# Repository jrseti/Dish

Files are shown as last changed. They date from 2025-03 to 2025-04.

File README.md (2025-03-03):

# Simple-Dish-Controller
Simple controller with toggle switches to move the motors of a satellite dish.

The project is to create a PCB that will control 2 motors tht will be used as the azimuth and elevation motors of a satellite dish. The direction will allow controlling simple movement for each motor, forward, reverse, still, all at one set speed.

The project usises Kicad to create the schematic, PCB and BOM.

This project fulfills 2 initiatives:
- Test out motor control
- Master Kicad for future projects
- Be the bas for a follow up PCB that will use a Rashberry Pi to control the motors

## Project Overview

This diagram simple shows the function of the project:

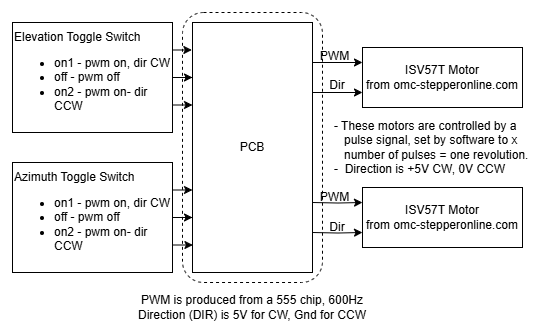
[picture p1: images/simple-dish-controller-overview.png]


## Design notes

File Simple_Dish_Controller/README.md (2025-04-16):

# Simple-Dish-Controller
Simple controller with toggle switches to move the motors of a satellite dish.

The project is to create a PCB that will control 2 motors tht will be used as the azimuth and elevation motors of a satellite dish. The direction will allow controlling simple movement for each motor, forward, reverse, still, all at one set speed.

The project uses Kicad to create the schematic, PCB and BOM.

This project fulfills 2 initiatives:
- Test out motor control
- Master Kicad for future projects
- Be the base for a follow up PCB that will use a Rashberry Pi to control the motors

## Project Overview

This diagram simply shows the function of the project: 

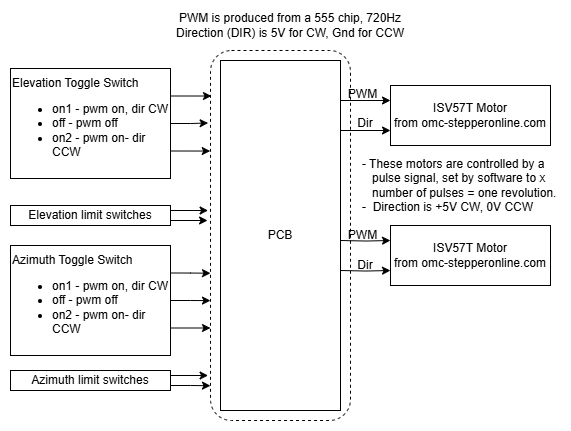
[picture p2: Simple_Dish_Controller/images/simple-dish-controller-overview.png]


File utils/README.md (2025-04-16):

# Utilities

A small set of Python utilitoes to aid in KiCad project management.

These scripts should commonly be run from the utils directory.

## Installation

Create a Python virtual environment if desired:
- python -m venv venv
- pip install -r requirements.txt

## create_3rd_party_table.py

Used to create a list of all the parts not contained in the standard KiCad. The distribution of these files is restricted due to license requirements. So a list of them is provided to the user for reference.

This script will:
- Read and parse a schematic file
- Any symbols from a library named DishFootprints will be recognized
- A list of the parts and symbol/footprint file URLs is created. This list is in the form of a GitHub markdown table for insertion into a README.md file.

Script invocation example:

```
python create_3rd_party_table.py ../Simple_Dish_Controller simple_dish_manual_controller.kicad_sch
```

Example output:

| Reference | Name | Manufacturer | Man PN | Distributor | Dist PN | Files |
|---|---|---|---|---|---|---|
| J3 | Screw Terminal Ground Chassis Vertical | Keystone Electronics | 7690 | Digikey | 36-7690-ND | https://www.digikey.com/en/models/151547  |
| J7,J5 | DE-15_VGA_FEMALE_CONN | Amphenol | L77HDE15SD1CH4FVGA | Digikey | L77HDE15SD1CH4FVGA-ND | https://www.digikey.com/en/models/4888525 |

## fix_kicad_symbols.py

For each symbol in a library make sure it has the required properties. This is useful information to fill in sybbols in a custom library.

The list is the following properties:

    - Value
    - Footprint
    - Datasheet
    - Description
    - Package
    - MF
    - MPN
    - DIS
    - DPN
    - Purchase_URL
    - Price
    - Note

Script invocation example:

```
python update_kicad_symbols.py ../third_party_symbols_and_footprints/DishSymbols.kicad_sym
```

The file DishSymbols.kicad_sym will be modified.

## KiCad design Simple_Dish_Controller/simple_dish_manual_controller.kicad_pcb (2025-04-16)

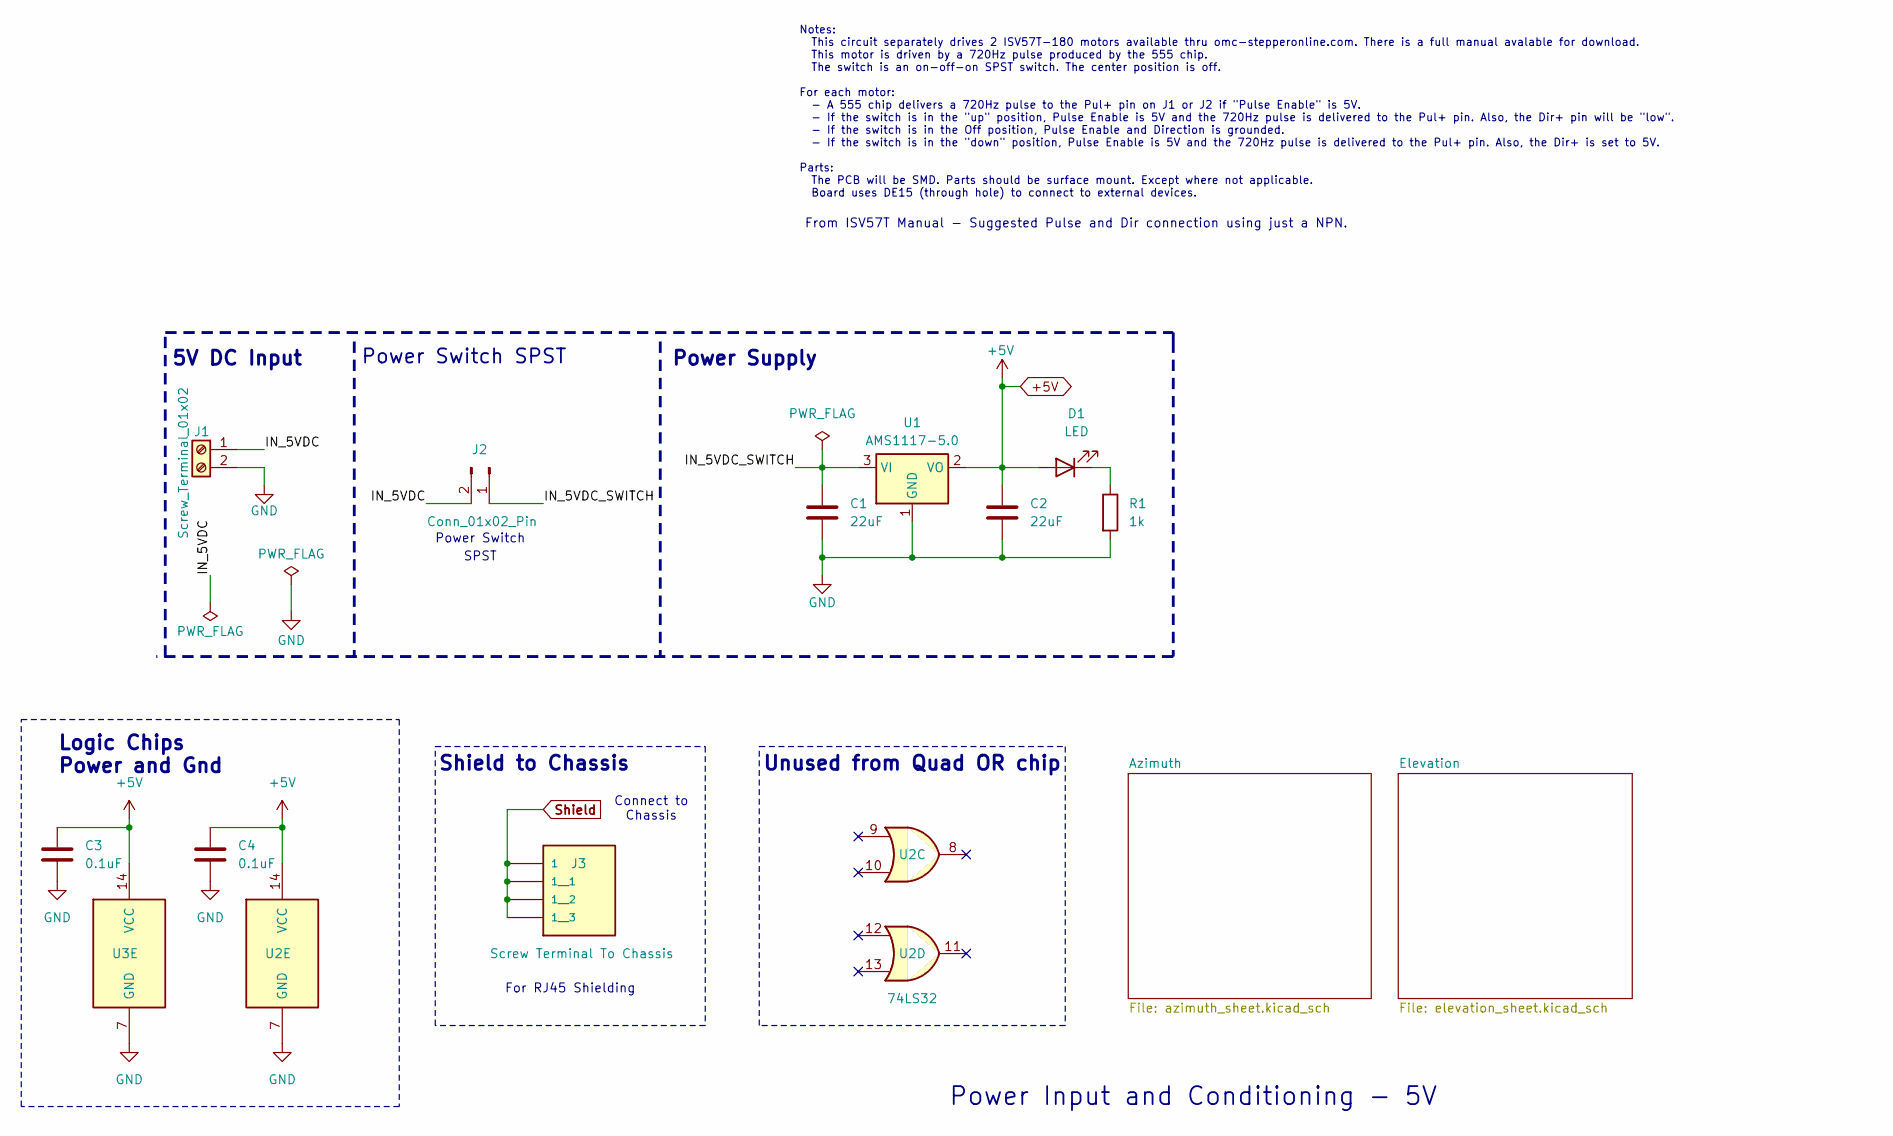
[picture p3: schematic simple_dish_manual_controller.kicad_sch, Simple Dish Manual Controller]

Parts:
C1, C2: 22uF; C_1206_3216Metric
C3, C4: 0.1uF; C_1206_3216Metric
D1: LED; LED_1206_3216Metric
J1: Screw_Terminal_01x02; TerminalBlock_Phoenix_MKDS-1,5-2-5.08_1x02_P5.08mm_Horizont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
J2: Conn_01x02_Pin; PinHeader_1x02_P2.54mm_Vertical
J3: Screw Terminal To Chassis; TERM_SCREW_01x04_VERTICAL_KEYSTONE_7690; PARTREV F
R1: 1k; R_0805_2012Metric
U1: AMS1117-5.0; SOT-223-3_TabPin2
U2: 74LS32; SOIC-14_3.9x8.7mm_P1.27mm
U3: 74LS08; SOIC-14_3.9x8.7mm_P1.27mm

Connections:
+5V: C2.1, C3.1, C4.1, D1.2 (A), U1.2 (VO), U2.14 (VCC), U3.14 (VCC); also elsewhere on the board
/IN_5VDC: J1.1, J2.2
/IN_5VDC_SWITCH: C1.1, J2.1, U1.3 (VI)
GND: C1.2, C2.2, C3.2, C4.2, J1.2, R1.2, U1.1 (GND), U2.7 (GND), U3.7 (GND); also elsewhere on the board
unnamed: D1.1 (K), R1.1
Shield: J3.1_1 (1), J3.1_2 (1__1), J3.1_3 (1__2), J3.1_4 (1__3); also elsewhere on the board

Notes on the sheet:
For RJ45 Shielding
Power Supply
5V DC Input
SPST
Connect to Chassis
Notes: This circuit separately drives 2 ISV57T-180 motors available thru omc-stepperonline.com. There is a full manual avalable for download. This motor is driven by a 720Hz pulse produced by the 555 chip. The switch is an on-off-on SPST switch. The center position is off. For each motor: - A 555 c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
Unused from Quad OR chip
Shield to Chassis
Logic Chips Power and Gnd
From ISV57T Manual - Suggested Pulse and Dir connection using just a NPN.
Power Switch SPST
Power Input and Conditioning - 5V
Power Switch

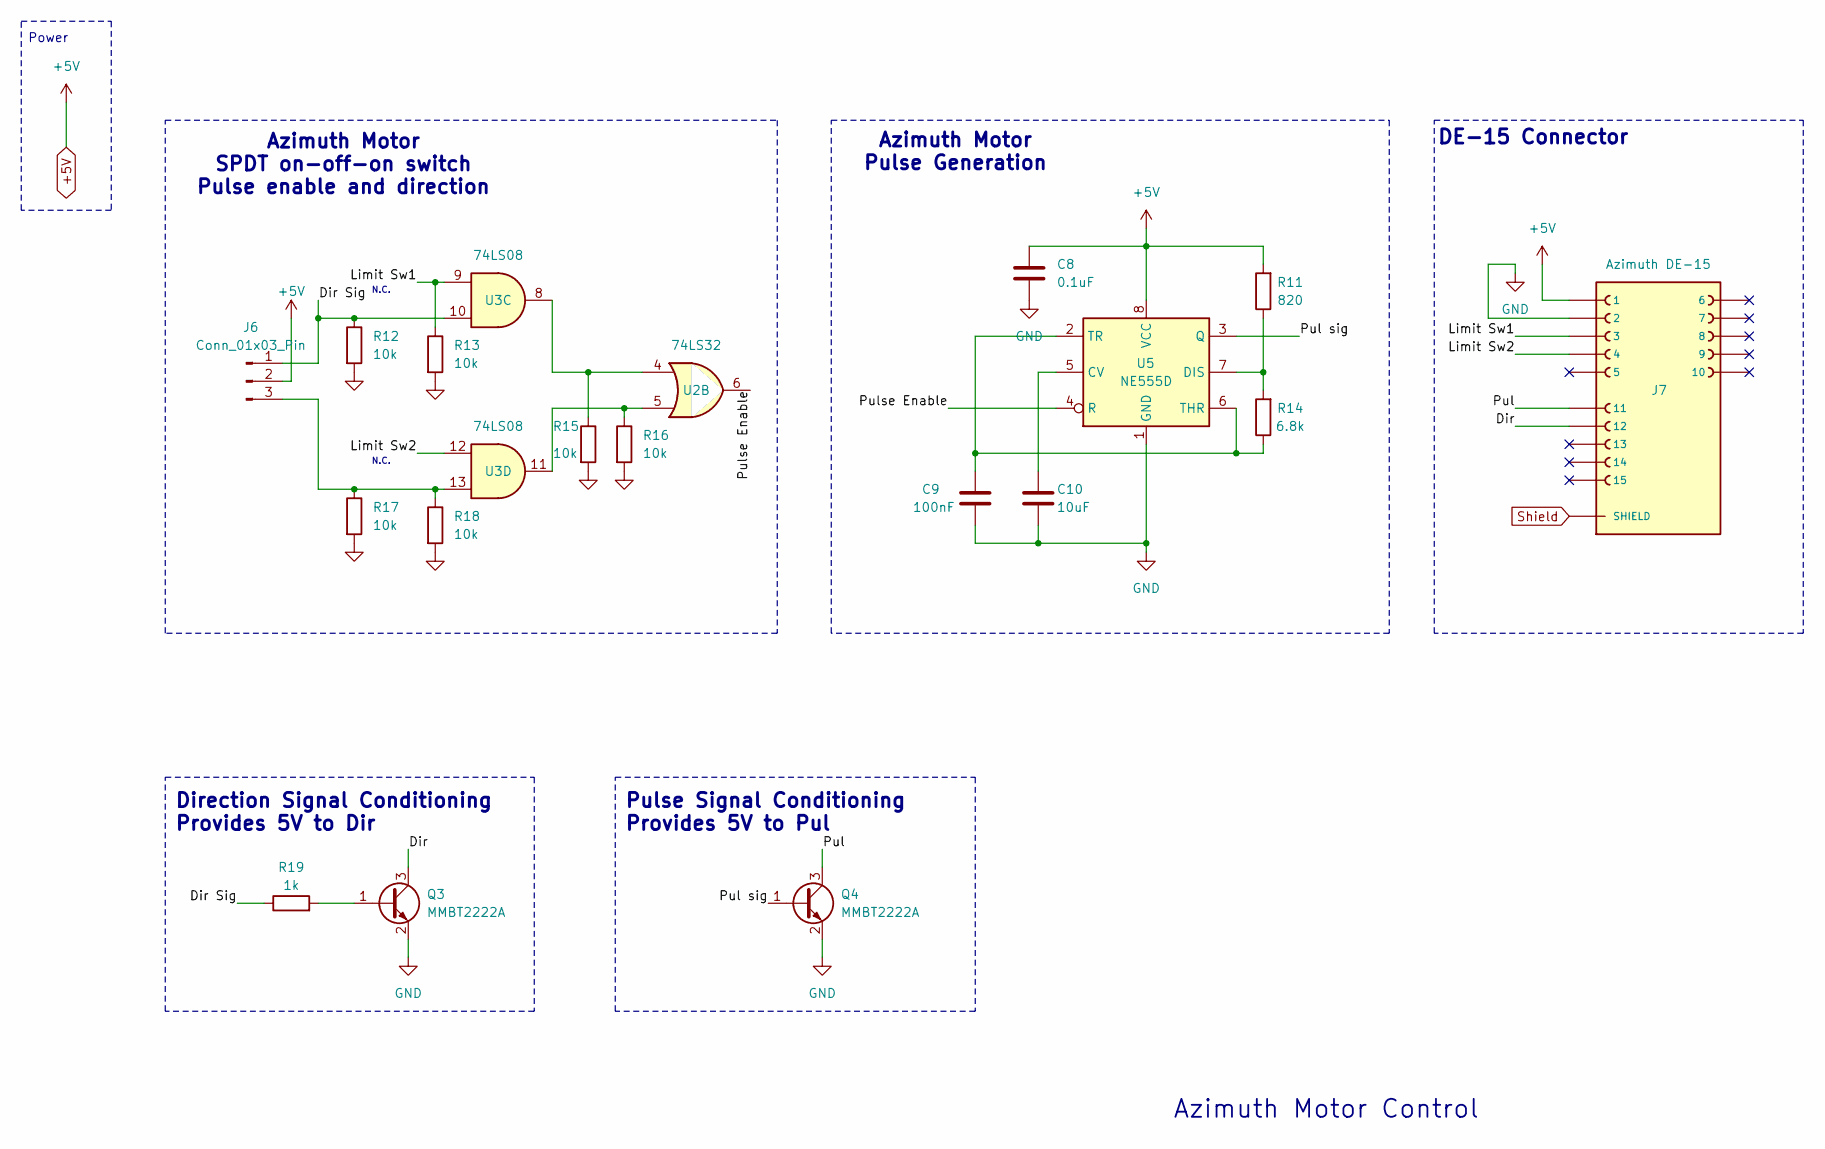
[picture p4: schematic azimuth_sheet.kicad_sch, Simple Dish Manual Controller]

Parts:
C8: 0.1uF; C_1206_3216Metric
C9: 100nF; C_1206_3216Metric
C10: 10uF; C_1206_3216Metric
J6: Conn_01x03_Pin; PinHeader_1x03_P2.54mm_Vertical
J7: Azimuth DE-15; DE15_VGA_FEMALE_CONN; PARTREV 1; DigiKey_Part_Number L77HDE15SD1CH4FVGA-ND
Q3, Q4: MMBT2222A; SOT-23
R11: 820; R_1206_3216Metric
R12, R13, R15, R16, R17, R18: 10k; R_1206_3216Metric
R14: 6.8k; R_1206_3216Metric
R19: 1k; R_1206_3216Metric
U2: 74LS32; SOIC-14_3.9x8.7mm_P1.27mm
U3: 74LS08; SOIC-14_3.9x8.7mm_P1.27mm
U5: NE555D; SOIC-8_3.9x4.9mm_P1.27mm

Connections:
+5V: C8.1, J6.2, J7.1, R11.2, U5.8 (VCC); also elsewhere on the board
/Azimuth/Dir: J7.12, Q3.3 (C)
/Azimuth/Dir Sig: J6.1, R12.1, R19.1, U3.10
/Azimuth/Limit Sw1: J7.3, R13.1, U3.9
/Azimuth/Limit Sw2: J7.4, U3.12
/Azimuth/Pul: J7.11, Q4.3 (C)
/Azimuth/Pul sig: Q4.1 (B), U5.3 (Q)
/Azimuth/Pulse Enable: U2.6, U5.4 (R)
GND: C8.2, C9.2, C10.2, J7.2, Q3.2 (E), Q4.2 (E), R12.2, R13.2, R15.2, R16.2, R17.2, R18.2, U5.1 (GND); also elsewhere on the board
unnamed: J6.3, R17.1, R18.1, U3.13
unnamed: Q3.1 (B), R19.2
unnamed: R15.1, U2.4, U3.8
unnamed: R16.1, U2.5, U3.11
unnamed: C10.1, U5.5 (CV)
unnamed: R11.1, R14.2, U5.7 (DIS)
unnamed: C9.1, R14.1, U5.2 (TR), U5.6 (THR)
Shield: J7.SH1 (SHIELD), J7.SH2 (SHIELD); also elsewhere on the board

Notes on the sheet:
Azimuth Motor Pulse Generation
Azimuth Motor SPDT on-off-on switch Pulse enable and direction
Azimuth Motor Control
N.C.
Direction Signal Conditioning Provides 5V to Dir
DE-15 Connector
Pulse Signal Conditioning Provides 5V to Pul
Power

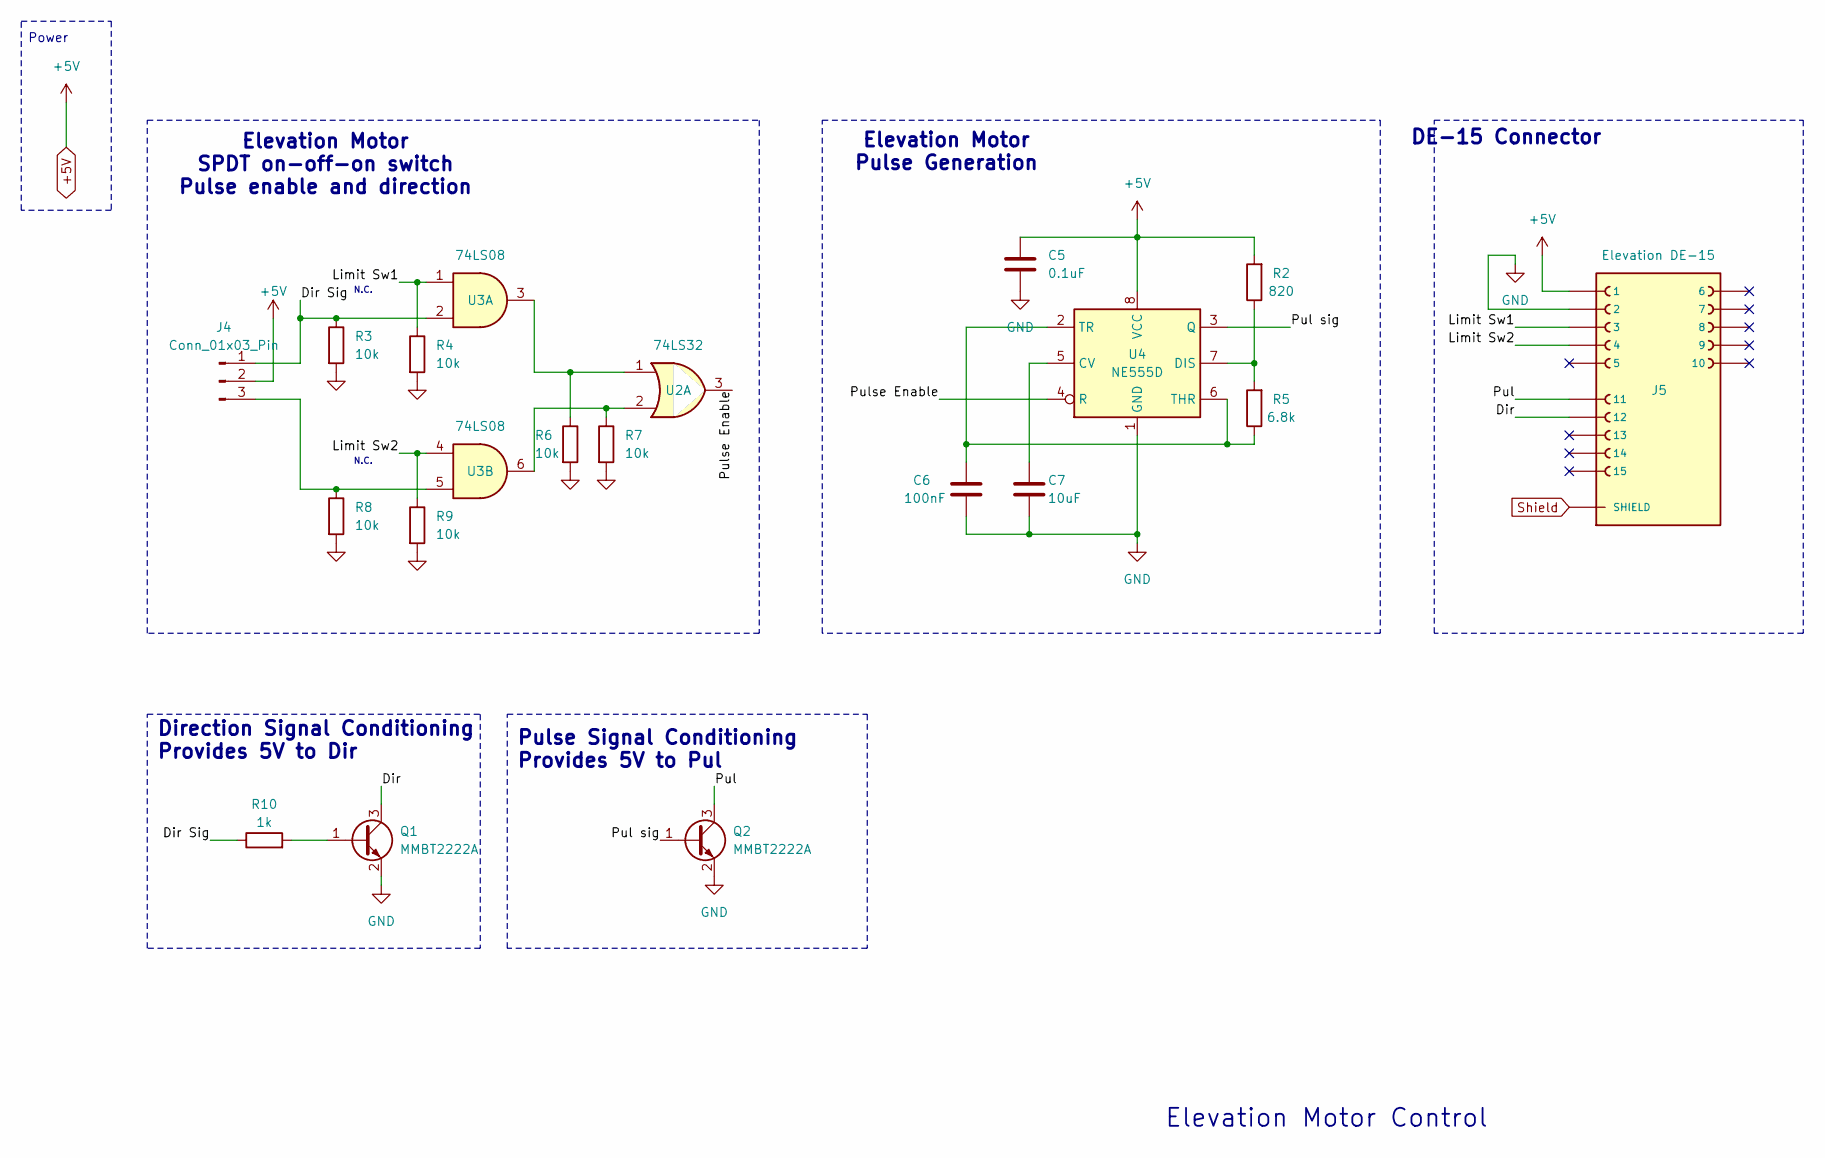
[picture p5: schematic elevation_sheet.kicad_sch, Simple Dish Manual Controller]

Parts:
C5: 0.1uF; C_1206_3216Metric
C6: 100nF; C_1206_3216Metric
C7: 10uF; C_1206_3216Metric
J4: Conn_01x03_Pin; PinHeader_1x03_P2.54mm_Vertical
J5: Elevation DE-15; DE15_VGA_FEMALE_CONN; PARTREV 1; DigiKey_Part_Number L77HDE15SD1CH4FVGA-ND
Q1, Q2: MMBT2222A; SOT-23
R2: 820; R_1206_3216Metric
R3, R4, R6, R7, R8, R9: 10k; R_1206_3216Metric
R5: 6.8k; R_1206_3216Metric
R10: 1k; R_1206_3216Metric
U2: 74LS32; SOIC-14_3.9x8.7mm_P1.27mm
U3: 74LS08; SOIC-14_3.9x8.7mm_P1.27mm
U4: NE555D; SOIC-8_3.9x4.9mm_P1.27mm

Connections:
+5V: C5.1, J4.2, J5.1, R2.2, U4.8 (VCC); also elsewhere on the board
/Elevation/Dir: J5.12, Q1.3 (C)
/Elevation/Dir Sig: J4.1, R3.1, R10.1, U3.2
/Elevation/Limit Sw1: J5.3, R4.1, U3.1
/Elevation/Limit Sw2: J5.4, R9.1, U3.4
/Elevation/Pul: J5.11, Q2.3 (C)
/Elevation/Pul sig: Q2.1 (B), U4.3 (Q)
/Elevation/Pulse Enable: U2.3, U4.4 (R)
GND: C5.2, C6.2, C7.2, J5.2, Q1.2 (E), Q2.2 (E), R3.2, R4.2, R6.2, R7.2, R8.2, R9.2, U4.1 (GND); also elsewhere on the board
unnamed: J4.3, R8.1, U3.5
unnamed: Q1.1 (B), R10.2
unnamed: R6.1, U2.1, U3.3
unnamed: R7.1, U2.2, U3.6
unnamed: C7.1, U4.5 (CV)
unnamed: R2.1, R5.2, U4.7 (DIS)
unnamed: C6.1, R5.1, U4.2 (TR), U4.6 (THR)
Shield: J5.SH1 (SHIELD), J5.SH2 (SHIELD); also elsewhere on the board

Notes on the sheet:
DE-15 Connector
Elevation Motor Control
Power
N.C.
Pulse Signal Conditioning Provides 5V to Pul
Elevation Motor SPDT on-off-on switch Pulse enable and direction
Elevation Motor Pulse Generation
Direction Signal Conditioning Provides 5V to Dir

Board: 4 copper layers, 46 parts (0 on the bottom side), 34 nets, no tracks yet.

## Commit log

2025-03-03 Added Kicad project files
    [simple_dish_manual_controller.kicad_pcb, simple_dish_manual_controller.kicad_sch]
2025-03-18 Simple changes
    [simple_dish_manual_controller.kicad_sch]
2025-03-19 Breaking up into sheets
    [simple_dish_manual_controller.kicad_sch]
2025-03-19 Broken into sheets
    [azimuth_sheet.kicad_sch, elevation_sheet.kicad_sch]
2025-03-20 Elevation sheet mostly complete
    [azimuth_sheet.kicad_sch, elevation_sheet.kicad_sch, simple_dish_manual_controller.kicad_sch]
2025-03-21 Added Azimuth
    [azimuth_sheet.kicad_sch, elevation_sheet.kicad_sch, simple_dish_manual_controller.kicad_sch]
2025-03-23 Latest versions
    [azimuth_sheet.kicad_sch, elevation_sheet.kicad_sch, simple_dish_manual_controller.kicad_pcb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]
2025-03-23 Updated C1 cap part path
    [azimuth_sheet.kicad_sch, elevation_sheet.kicad_sch, simple_dish_manual_controller.kicad_pcb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]
2025-03-23 Added RJ45 ports
    [azimuth_sheet.kicad_sch, elevation_sheet.kicad_sch, simple_dish_manual_controller.kicad_sch]
2025-03-23 Footprints defined - passes ERC
    [azimuth_sheet.kicad_sch, elevation_sheet.kicad_sch, simple_dish_manual_controller.kicad_sch]
2025-03-23 777 chip is now SMD
    [azimuth_sheet.kicad_sch, elevation_sheet.kicad_sch, simple_dish_manual_controller.kicad_pcb]
2025-03-28 Added parts dir
    [azimuth_sheet.kicad_sch, elevation_sheet.kicad_sch, simple_dish_manual_controller.kicad_pcb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]
2025-03-31 Still creating parts libraries
    [azimuth_sheet.kicad_sch, elevation_sheet.kicad_sch, simple_dish_manual_controller.kicad_sch]
2025-03-31 More parts defined
    [azimuth_sheet.kicad_sch, elevation_sheet.kicad_sch]
2025-04-04 Latest update
    [azimuth_sheet.kicad_sch, elevation_sheet.kicad_sch, simple_dish_manual_controller.kicad_pcb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]
2025-04-15 Added back in fp-lib-table and sym-lib-table
    [simple_dish_manual_controller.kicad_sch]
2025-04-15 minor update to PCB
    [simple_dish_manual_controller.kicad_pcb]
2026-08-10 Replace Python .gitignore with KiCad-aware rules
    The stock GitHub Python template ignored lib/, build/ and parts/ -- all of
    which collide with KiCad library, fab output and firmware conventions --
    while ignoring none of what KiCad actually generates.
    Now ignores backups, autosaves, .kicad_prl, regenerated netlists, ERC/DRC
    scratch reports, stray fab zips and firmware build output. Keeps
    launch.json and tasks.json tracked at any depth: the **/ prefix on the
    .vscode rules is required because a pattern containing a slash is anchored
    to the .gitignore's own directory and would miss software/.vscode/.
2026-08-10 Rename firmware project to rcm_dish_controller and add datasheets
    Renames axis_controller_lqfp64_rev10.ioc -> rcm_dish_controller.ioc,
    including the ProjectManager.ProjectName and ProjectFileName fields inside
    the file, the TARGET in all three Makefiles, and the cortex-debug
    executable path in launch.json. Leaving the internal ProjectManager fields
    stale would make CubeMX regenerate under the old name on next open.
    Verified: make exits 0 and links build/rcm_dish_controller.elf
    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
2026-08-10 Add README and design plan for the CM4 carrier
    Documents the board as the Axis Commander with a CM4 added on board.
    Nothing from the original is removed -- the CM4 is additive, giving an
    on-board host alongside the external RS485 host already supported.
    Records the constraint that drove the host-link design: all three usable
    STM32 UARTs are allocated (USART1 = RS485 device, USART3 = RS485 leader,
    LPUART1 = GPS NMEA) and ~46 of roughly 50 available I/O are assigned on
    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
2026-08-13 Updates to power
2026-08-18 CM4 schematic changes, before renumbering
2026-08-26 CAN looks complete in schematic
2026-09-01 Before removing CAN 24V
2026-09-04 Added kicad dir
2026-09-04 Added stepper_controller and encoder_sensors
2026-09-19 Add cm4-robo-controller KiCad project
    Initial commit of the robo-dc-controller CM4 board: schematic sheets,
    PCB, project settings, library tables, and design notes.
    Widen the .bak ignore rule to *.bak* so dated schematic backups
    (e.g. power.kicad_sch.bak-noise-20260907-203215) stay out of the repo.
2026-09-20 Fixing up usb.kicad+sch
